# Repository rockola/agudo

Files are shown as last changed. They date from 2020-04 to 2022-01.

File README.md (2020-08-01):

# agudo
Phase 45

Board size 28.9mmx54.1mm, 1/8W resistors, SMD JFETs

* v0.1: initial version, verified

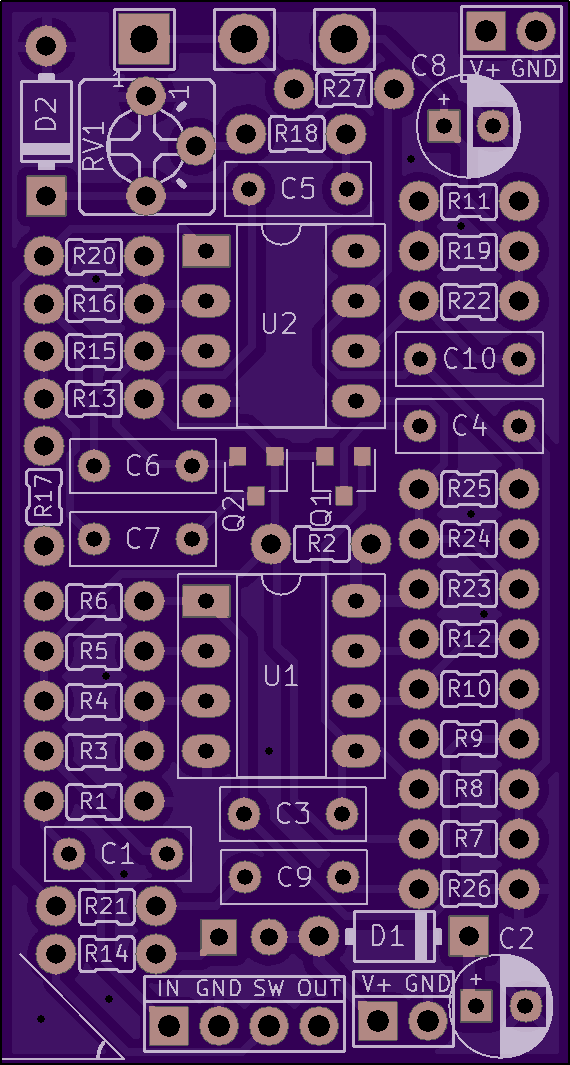
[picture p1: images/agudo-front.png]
Front

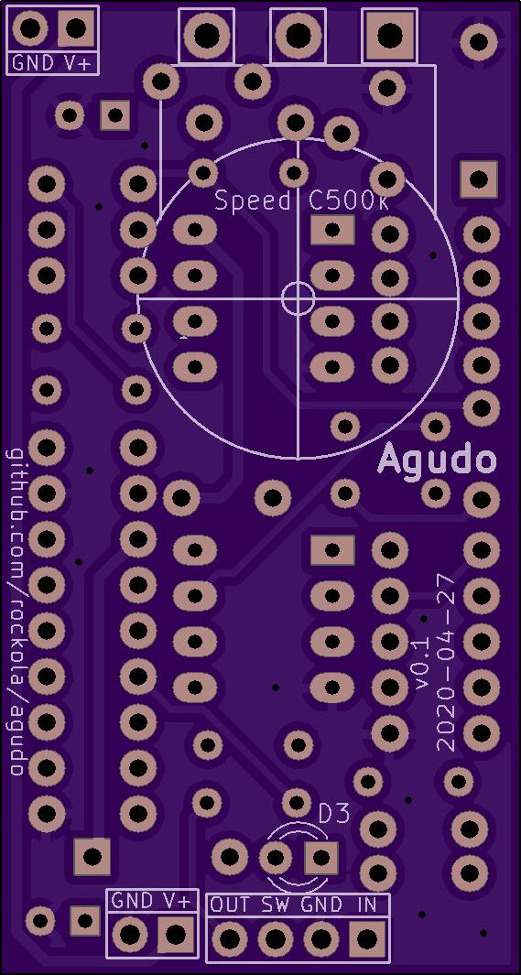
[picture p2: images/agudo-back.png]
Back


## LICENSE

MIT License (see LICENSE.md)

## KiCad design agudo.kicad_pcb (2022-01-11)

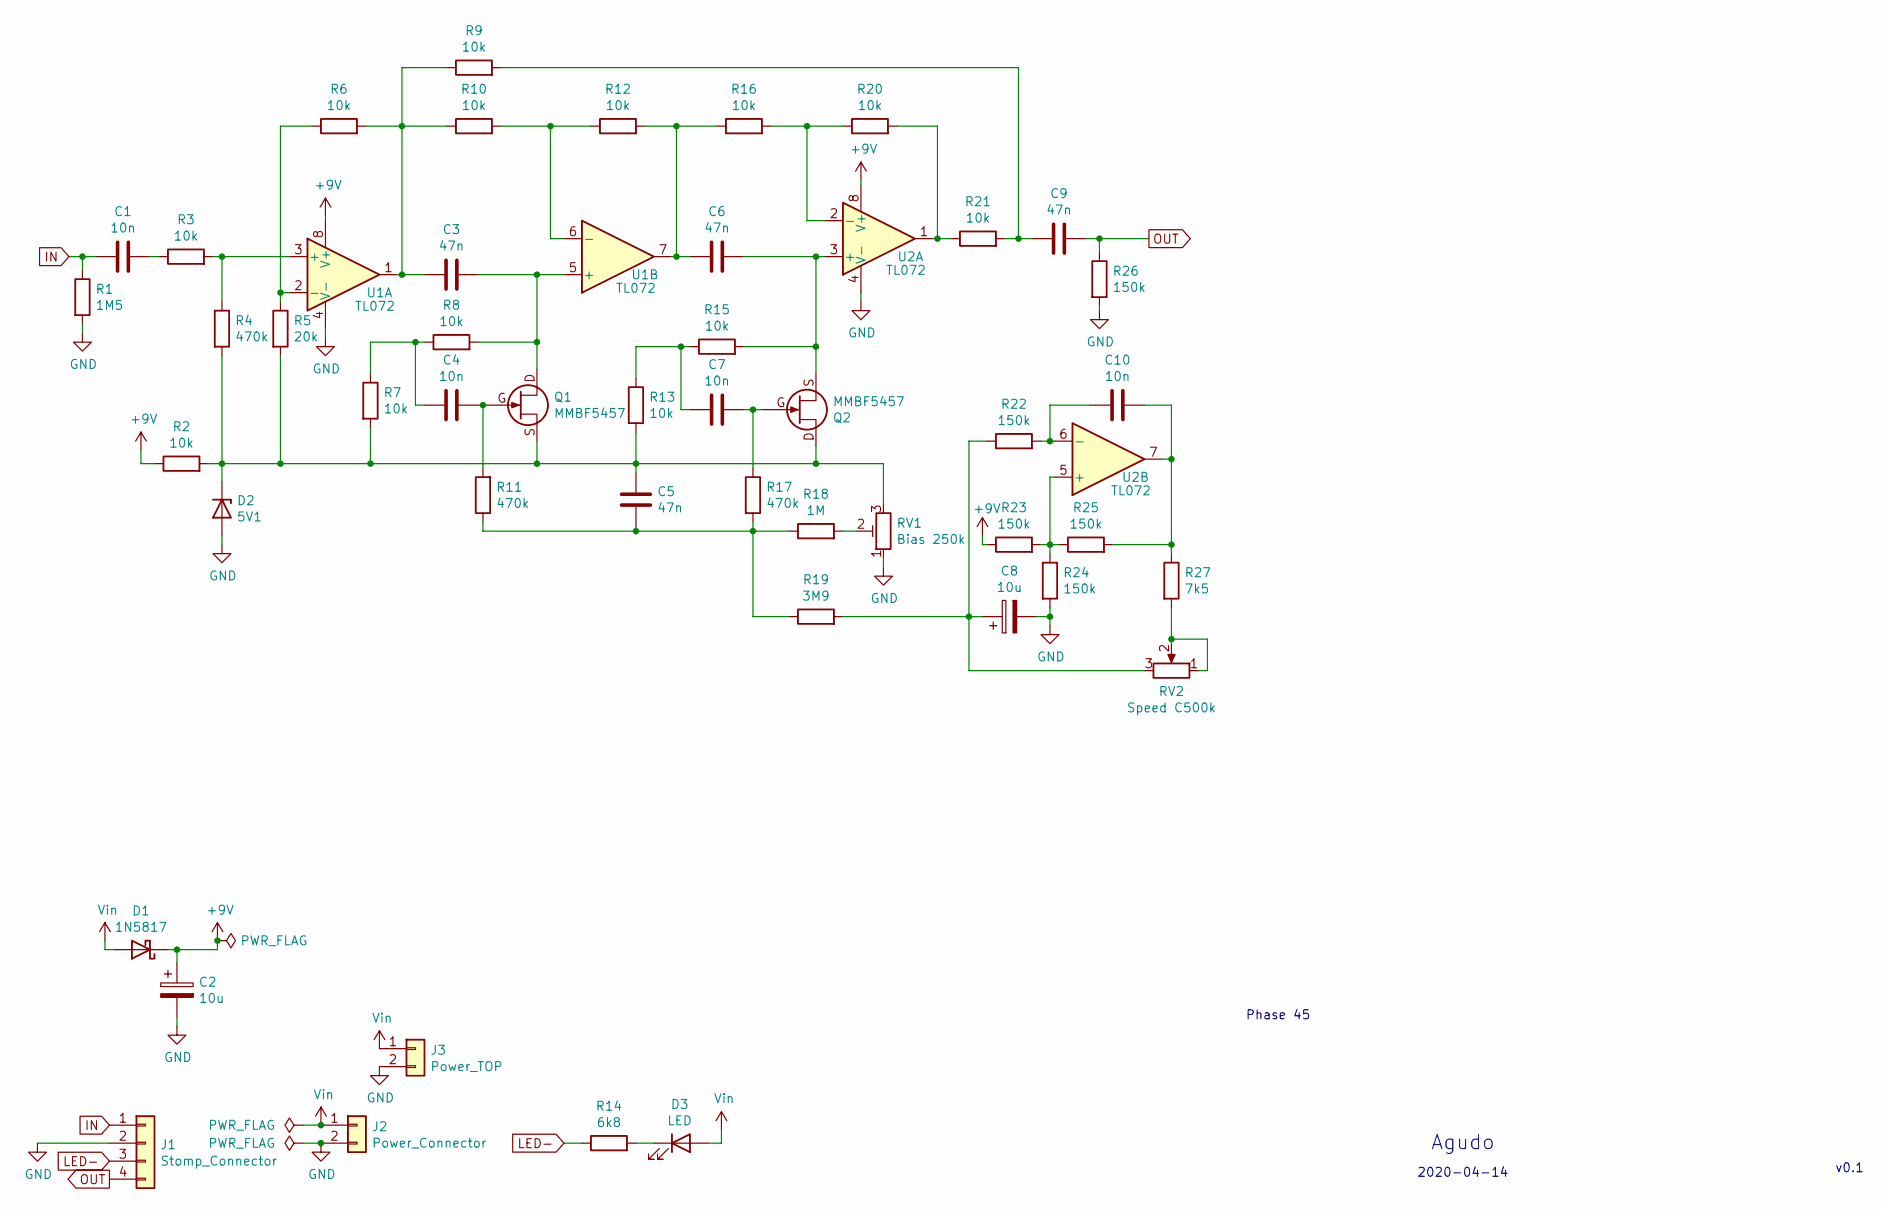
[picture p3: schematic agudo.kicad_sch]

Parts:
C1, C4, C7, C10: 10n; C_Box_7.2_2.5
C2, C8: 10u; CP_D5.0_P2.50
C3, C5, C6, C9: 47n; C_Box_7.2_2.5
D1: 1N5817; DO41-3
D2: 5V1; DO41-3
D3: LED; LED_D3.0mm
J1: Stomp_Connector; Stomp_4pin
J2: Power_Connector; Power_Header_2pin
J3: Power_TOP; Power_Header_2pin_TOP
Q1, Q2: MMBF5457; SOT-23_NJFET_DSG
R1: 1M5; R_0.125W_5mm
R2, R3, R6, R7, R8, R9, R10, R12, R13, R15, R16, R20, R21: 10k; R_0.125W_5mm
R4, R11, R17: 470k; R_0.125W_5mm
R5: 20k; R_0.125W_5mm
R14: 6k8; R_0.125W_5mm
R18: 1M; R_0.125W_5mm
R19: 3M9; R_0.125W_5mm
R22, R23, R24, R25, R26: 150k; R_0.125W_5mm
R27: 7k5; R_0.125W_5mm
RV1: Bias 250k; TRIM1
RV2: Speed C500k; 16mm_BoardMount
U1, U2: TL072; DIP-8_W7.62mm_Socket_LongPads

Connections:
+9V: C2.1, D1.1 (K), R2.1, R23.1, U1.8 (V+), U2.8 (V+)
GND: C2.2, C8.2, D2.2 (A), J1.2 (GND), J2.2 (GND), J3.2 (GND), R1.2, R24.2, R26.2, RV1.1, U1.4 (V-), U2.4 (V-)
IN: C1.1, J1.1 (IN), R1.1
LED-: J1.3 (SW), R14.1
unnamed: C1.2, R3.1
unnamed: C3.1, R6.2, R9.1, R10.1, U1.1
unnamed: C3.2, Q1.D, R8.2, U1.5 (+)
unnamed: C4.1, R7.1, R8.1
unnamed: C4.2, Q1.G, R11.2
unnamed: C5.1, D2.1 (K), Q1.S, Q2.D, R2.2, R4.2, R5.2, R7.2, R13.2, RV1.3
unnamed: C5.2, R11.1, R17.2, R18.1, R19.1
unnamed: C6.1, R12.2, R16.1, U1.7
unnamed: C6.2, Q2.S, R15.2, U2.3 (+)
unnamed: C7.1, R13.1, R15.1
unnamed: C7.2, Q2.G, R17.1
unnamed: C8.1, R19.2, R22.1, RV2.3
unnamed: C9.1, R9.2, R21.2
unnamed: C10.1, R22.2, U2.6 (-)
unnamed: C10.2, R25.2, R27.1, U2.7
unnamed: D3.1 (K), R14.2
unnamed: R3.2, R4.1, U1.3 (+)
unnamed: R5.1, R6.1, U1.2 (-)
unnamed: R10.2, R12.1, U1.6 (-)
unnamed: R16.2, R20.1, U2.2 (-)
unnamed: R18.2, RV1.2
unnamed: R20.2, R21.1, U2.1
unnamed: R23.2, R24.1, R25.1, U2.5 (+)
unnamed: R27.2, RV2.1, RV2.2
OUT: C9.2, J1.4 (OUT), R26.1
VIN: D1.2 (A), D3.2 (A), J2.1 (PWR), J3.1 (PWR)

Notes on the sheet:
Phase 45
Agudo
v0.1
2020-04-14

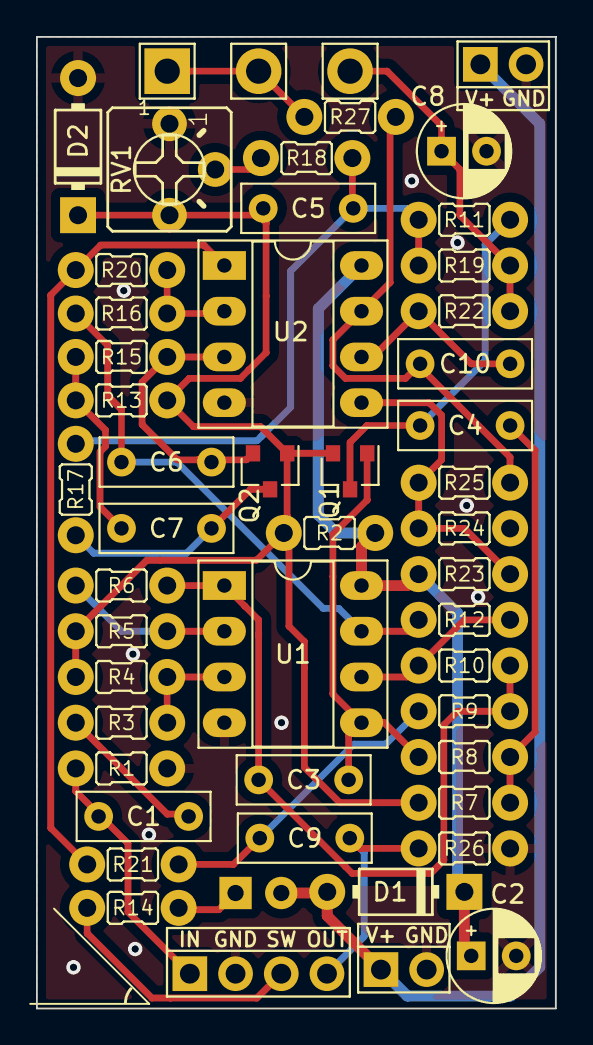
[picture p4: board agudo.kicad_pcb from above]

Board: 2 copper layers, 28.8 x 54.0 mm, 49 parts (1 on the bottom side), 30 nets.

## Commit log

2020-04-29 slight silkscreen change; Gerbers sent to oshpark
    [agudo-B_Cu.gbr, agudo-B_Mask.gbr, agudo-B_Paste.gbr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]
2020-04-29 board size note
2020-08-01 Update README.md
    v0.1 board not really 1590A compatible - board fits but jacks/stomp do not have enough space
2022-01-11 updated to KiCad 6.0
    [agudo-B_Cu.gbr, agudo-B_Mask.gbr, agudo-B_Paste.gbr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]
